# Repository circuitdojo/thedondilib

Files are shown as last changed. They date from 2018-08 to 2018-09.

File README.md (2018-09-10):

# The Dondi Lib

Part nightlight, part art, part Internet of Things. This little bluetooth enabled box will surprise and delight. For more info go [here](https://www.hackster.io/jaredwolff/the-dondi-lib-a-bluetooth-low-energy-light-box-cc7d90).

## Version One

### Features

1. Bluetooth Low Energy with a Rigado BMD-300 (nRF52832)
1. Lithium Battery support
1. Motion support
1. PIR Amplifier (Motion)
1. External connections for button, DC power, battery and PIR
1. Tag-Connect SWD connection

### Rework

Please note that this is Version 1 of the board. There are several (reworkable) issues with this board. 

1. U7A.1 should be connected to D9.C
1. D4.2 should be connected to VDC
1. J2.1 missing connection to VSYS
1. U2 changed to a LED1642GW
1. Untuffed U6 to accomodate LED driver above
1. LED_OE (PWM_CLK) connected to LIS2DH_INT

### License

Released under the Creative Commons Attribution-NonCommercial-NoDerivatives 4.0 International Public License. More info [here](https://creativecommons.org/licenses/by-nc-nd/4.0/legalcode).

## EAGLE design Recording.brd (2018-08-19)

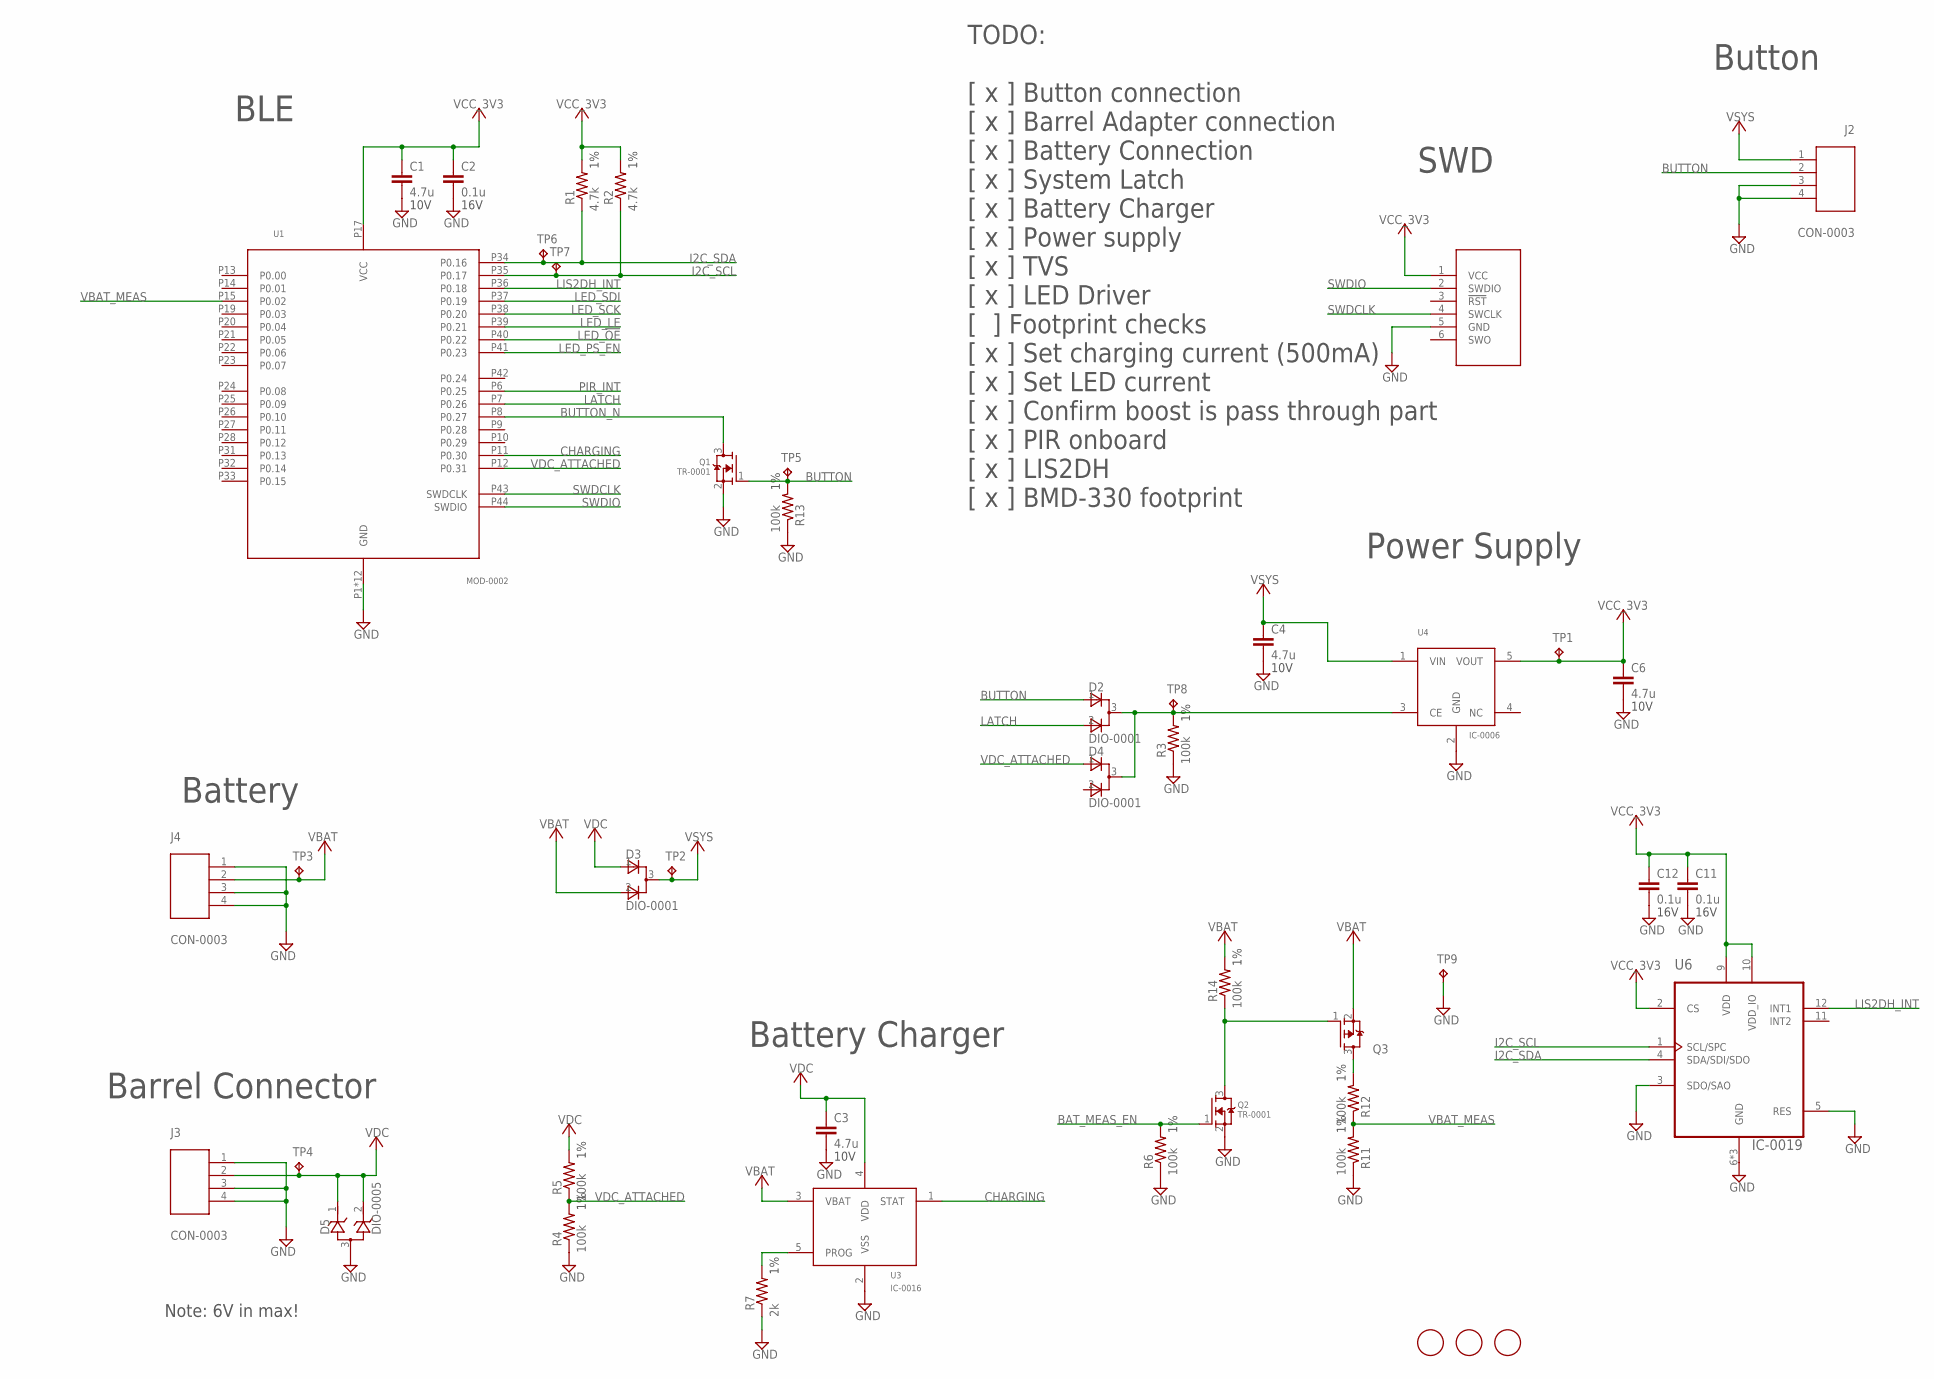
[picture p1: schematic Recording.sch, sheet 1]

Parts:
C1, C3, C4, C6: 4.7u; C0603
C2, C11, C12: 0.1u; C0603
D2, D3, D4: DIO-0001; SOT23
D5: DIO-0005; SOT23
J1: CON-0002; TC2030-MCP-NL
J2, J3, J4: CON-0003; CON-SM02B-SRSS-TB(LF)(SN)
Q1, Q2: TR-0001; SOT23
Q3: TR-0003; SOT23
R1, R2: 4.7k; R0603
R3, R4, R5, R6, R11, R12, R13, R14: 100k; R0603
R7: 2k; R0603
TP1, TP2, TP3, TP4, TP5, TP6, TP7, TP8, TP9: TP-0001; TP-1P27
U1: MOD-0002; MODULE-BMD-300
U3: IC-0016; SOT23-5
U4: IC-0006; SOT23-5
U6: IC-0019; PQFN50P200X200100-12N
U$1, U$2, U$3: FIDUCIAL; FIDUCIAL_1MM

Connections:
BAT_MEAS_EN: Q2.1 (G), R6.2
BAT_MEAS_P_GATE: Q2.3 (D), Q3.1 (G), R14.1
BUTTON: D2.1 (A1), J2.2, Q1.1 (G), R13.2, TP5.P$1, TP5.P$2, TP5.TP
BUTTON_N: Q1.3 (D), U1.P8 (P0.27)
CHARGER_PROG: R7.2, U3.5 (PROG)
CHARGING: U1.P11 (P0.30), U3.1 (STAT)
GND: C1.2, C2.2, C3.2, C4.2, C6.2, C11.2, C12.2, D5.3 (A), J1.5 (GND), J2.3, J2.4, J3.1, J3.3, J3.4, J4.1, J4.3, J4.4, Q1.2 (S), Q2.2 (S), R3.1, R4.1, R6.1, R7.1, R11.1, R13.1, TP9.P$1, TP9.P$2, TP9.TP, U1.P1 (GND), U1.P2 (GND), U1.P3 (GND), U1.P4 (GND), U1.P5 (GND), U1.P16 (GND), U1.P18 (GND), U1.P29 (GND), U1.P30 (GND), U1.P45 (GND), U1.P46 (GND), U1.P47 (GND), U3.2 (VSS), U4.2 (GND), U6.3 (SDO/SAO), U6.5 (RES), U6.6 (GND), U6.7 (GND), U6.8 (GND); also elsewhere on the board
I2C_SCL: R2.1, TP7.P$1, TP7.P$2, TP7.TP, U1.P35 (P0.17), U6.1 (SCL/SPC)
I2C_SDA: R1.1, TP6.P$1, TP6.P$2, TP6.TP, U1.P34 (P0.16), U6.4 (SDA/SDI/SDO)
LATCH: D2.2 (A2), U1.P7 (P0.26)
LED_!OE: U1.P40 (P0.22); also elsewhere on the board
LED_LE: U1.P39 (P0.21); also elsewhere on the board
LED_PS_EN: U1.P41 (P0.23); also elsewhere on the board
LED_SCK: U1.P38 (P0.20); also elsewhere on the board
LED_SDI: U1.P37 (P0.19); also elsewhere on the board
LIS2DH_INT: U1.P36 (P0.18), U6.12 (INT1)
PIR_INT: U1.P6 (P0.25); also elsewhere on the board
SWDCLK: J1.4 (SWCLK), U1.P43 (SWDCLK)
SWDIO: J1.2 (SWDIO), U1.P44 (SWDIO)
VBAT: D3.2 (A2), J4.2, Q3.2 (S), R14.2, TP3.P$1, TP3.P$2, TP3.TP, U3.3 (VBAT)
VBAT_MEAS: R11.2, R12.1, U1.P15 (P0.02)
VBAT_SW: Q3.3 (D), R12.2
VCC_3V3: C1.1, C2.1, C6.1, C11.1, C12.1, J1.1 (VCC), R1.2, R2.2, TP1.P$1, TP1.P$2, TP1.TP, U1.P17 (VCC), U4.5 (VOUT), U6.2 (CS), U6.9 (VDD), U6.10 (VDD_IO); also elsewhere on the board
VCC_3V3_EN: D2.3 (C), D4.3 (C), R3.2, TP8.P$1, TP8.P$2, TP8.TP, U4.3 (CE)
VDC: C3.1, D3.1 (A1), D5.1 (C1), D5.2 (C2), J3.2, R5.2, TP4.P$1, TP4.P$2, TP4.TP, U3.4 (VDD)
VDC_ATTACHED: D4.1 (A1), R4.2, R5.1, U1.P12 (P0.31)
VSYS: C4.1, D3.3 (C), TP2.P$1, TP2.P$2, TP2.TP, U4.1 (VIN); also elsewhere on the board

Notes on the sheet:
TODO: [ x ] Button connection [ x ] Barrel Adapter connection [ x ] Battery Connection [ x ] System Latch [ x ] Battery Charger [ x ] Power supply [ x ] TVS [ x ] LED Driver [ ] Footprint checks [ x ] Set charging current (500mA) [ x ] Set LED current [ x ] Confirm boost is pass through part [ x ] 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
Button
SWD
BLE
Battery
Barrel Connector
Note: 6V in max!
Battery Charger
Power Supply

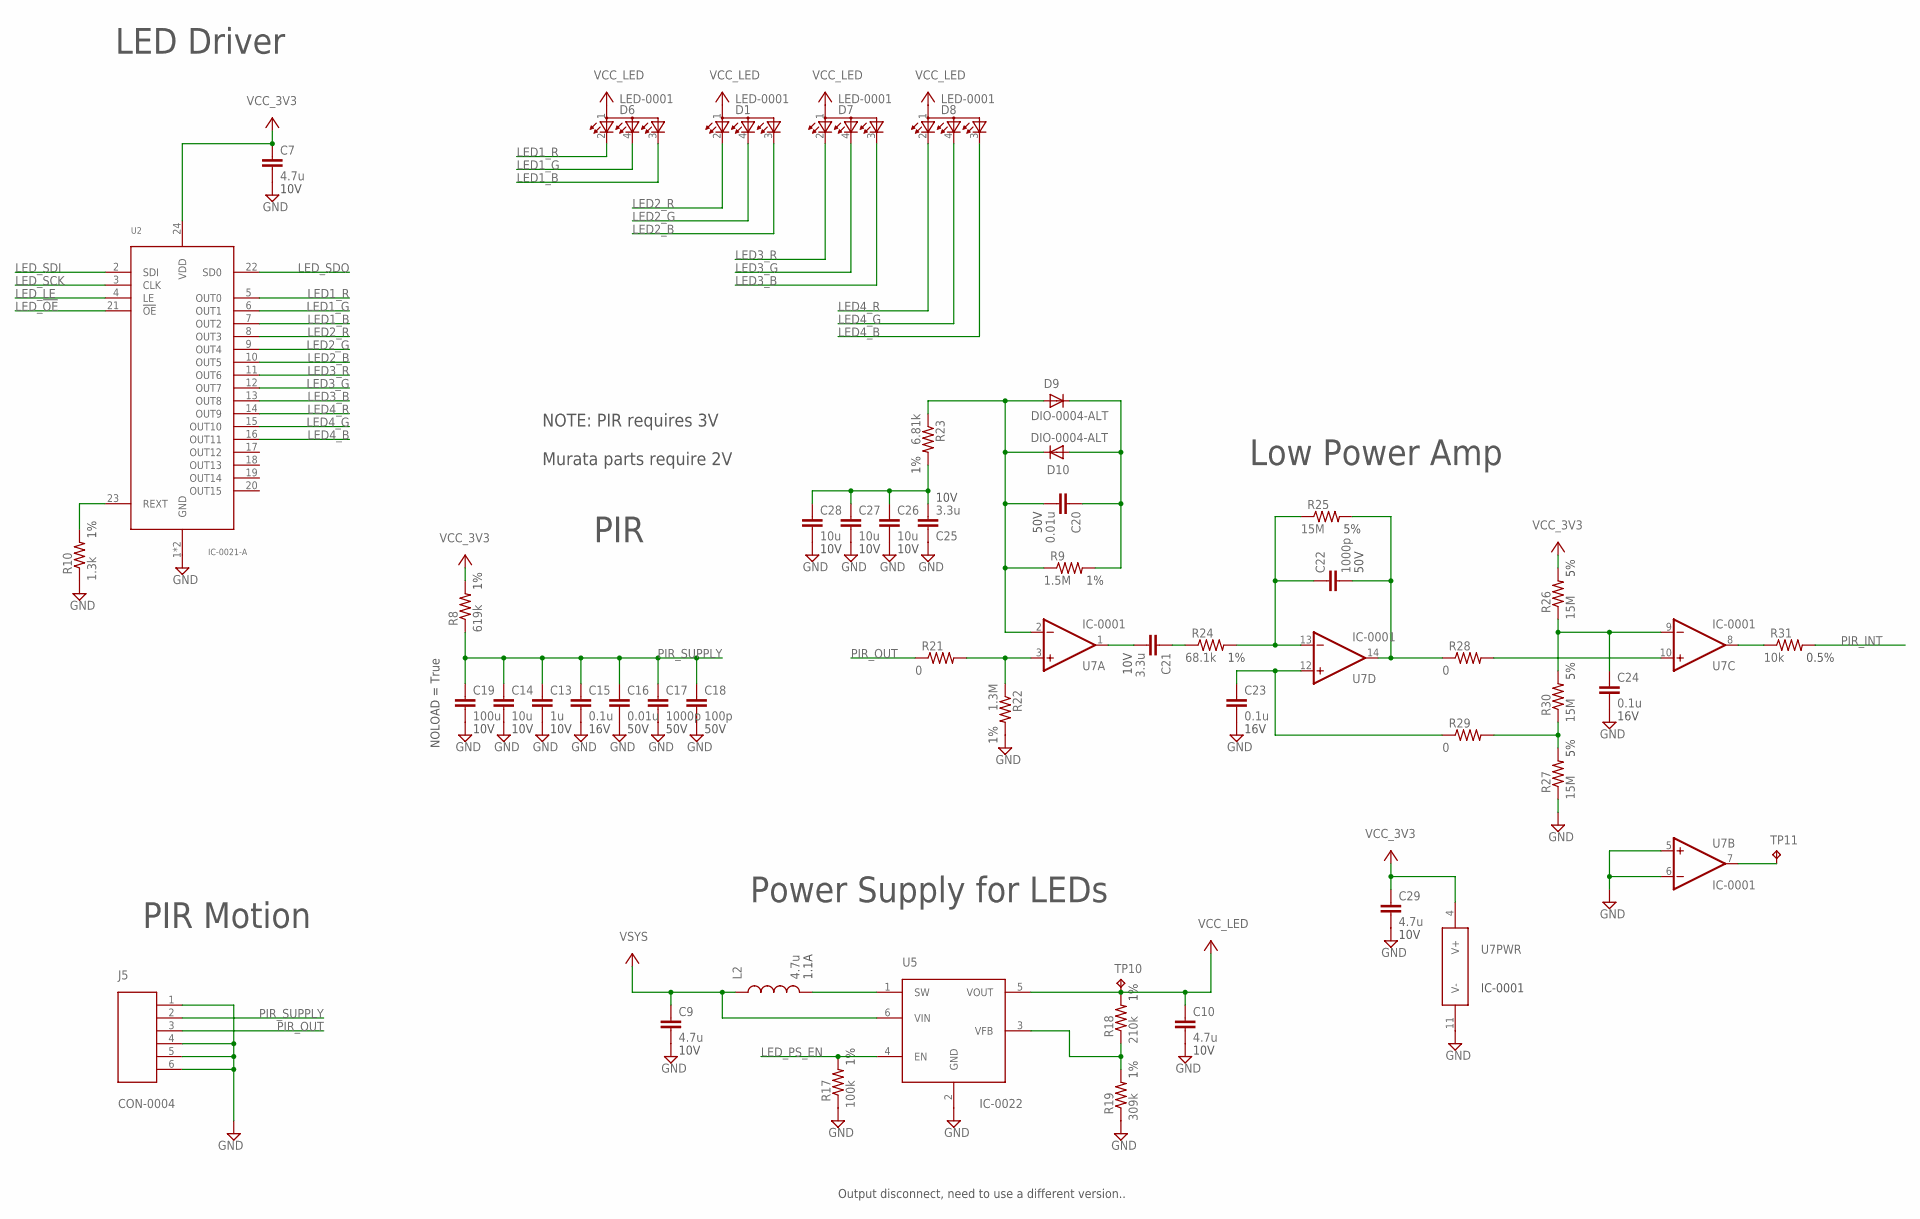
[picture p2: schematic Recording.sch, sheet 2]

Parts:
C7, C9, C10, C29: 4.7u; C0603
C13: 1u; C0603
C14, C26, C27, C28: 10u; C0805
C15, C23, C24: 0.1u; C0603
C16, C20: 0.01u; C0603
C17, C22: 1000p; C0603
C18: 100p; C0603
C19: 100u; C1210
C21, C25: 3.3u; C0603
D1, D6, D7, D8: LED-0001; LED_ASMB-KTF0-0A306
D9, D10: DIO-0004-ALT; SOD523
J5: CON-0004; CON-SM04B-SRSS-TB(LF)(SN)
L2: 4.7u; IND-2P0X2P0X1P2
R8: 619k; R0603
R9: 1.5M; R0603
R10: 1.3k; R0603
R17: 100k; R0603
R18: 210k; R0603
R19: 309k; R0603
R21, R28, R29: 0; R0603
R22: 1.3M; R0603
R23: 6.81k; R0603
R24: 68.1k; R0603
R25, R26, R27, R30: 15M; R0603
R31: 10k; R0603
TP10, TP11: TP-0001; TP-1P27
U2: IC-0021-A; SOP65P640X120-25N
U5: IC-0022; SOT23-6
U7: IC-0001; TSSOP14

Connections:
BOOST_FB: R18.1, R19.2, U5.3 (VFB)
BOOST_SW: L2.P$2 (2), U5.1 (SW)
GND: C7.2, C9.2, C10.2, C13.2, C14.2, C15.2, C16.2, C17.2, C18.2, C19.2, C23.2, C24.2, C25.1, C26.2, C27.2, C28.2, C29.2, J5.1, J5.4, J5.5, J5.6, R10.1, R17.1, R19.1, R22.2, R27.1, U2.1 (GND), U2.25 (GND), U5.2 (GND), U7.5 (+IN), U7.6 (-IN), U7.11 (V-); also elsewhere on the board
LED1_B: D6.3 (CGREEN), U2.7 (OUT2)
LED1_G: D6.4 (CBLUE), U2.6 (OUT1)
LED1_R: D6.2 (CRED), U2.5 (OUT0)
LED2_B: D1.3 (CGREEN), U2.10 (OUT5)
LED2_G: D1.4 (CBLUE), U2.9 (OUT4)
LED2_R: D1.2 (CRED), U2.8 (OUT3)
LED3_B: D7.3 (CGREEN), U2.13 (OUT8)
LED3_G: D7.4 (CBLUE), U2.12 (OUT7)
LED3_R: D7.2 (CRED), U2.11 (OUT6)
LED4_B: D8.3 (CGREEN), U2.16 (OUT11)
LED4_G: D8.4 (CBLUE), U2.15 (OUT10)
LED4_R: D8.2 (CRED), U2.14 (OUT9)
LED_!OE: U2.21 (!OE); also elsewhere on the board
LED_LE: U2.4 (LE); also elsewhere on the board
LED_PS_EN: R17.2, U5.4 (EN); also elsewhere on the board
LED_REXT: R10.2, U2.23 (REXT)
LED_SCK: U2.3 (CLK); also elsewhere on the board
LED_SDI: U2.2 (SDI); also elsewhere on the board
LED_SDO: U2.22 (SD0)
unnamed: C20.2, D9.A, D10.C, R9.1, R23.1, U7.2 (-IN)
unnamed: TP11.P$1, TP11.P$2, TP11.TP, U7.7 (OUT)
unnamed: C20.1, D9.C, D10.A, R9.2
unnamed: R21.2, R22.1, U7.3 (+IN)
unnamed: C25.2, C26.1, C27.1, C28.1, R23.2
unnamed: C21.2, U7.1 (OUT)
unnamed: C21.1, R24.1
unnamed: C22.1, R24.2, R25.1, U7.13 (-IN)
unnamed: C22.2, R25.2, R28.1, U7.14 (OUT)
unnamed: C23.1, R29.1, U7.12 (+IN)
unnamed: R28.2, U7.10 (+IN)
unnamed: R27.2, R29.2, R30.1
unnamed: C24.1, R26.1, R30.2, U7.9 (-IN)
PIR_INT: R31.2; also elsewhere on the board
PIR_INT_CL: R31.1, U7.8 (OUT)
PIR_OUT: J5.3, R21.1
PIR_SUPPLY: C13.1, C14.1, C15.1, C16.1, C17.1, C18.1, C19.1, J5.2, R8.1
VCC_3V3: C7.1, C29.1, R8.2, R26.2, U2.24 (VDD), U7.4 (V+); also elsewhere on the board
VCC_LED: C10.1, D1.1 (A2), D6.1 (A2), D7.1 (A2), D8.1 (A2), R18.2, TP10.P$1, TP10.P$2, TP10.TP, U5.5 (VOUT)
VSYS: C9.1, L2.P$1 (1), U5.6 (VIN); also elsewhere on the board

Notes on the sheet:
PIR Motion
Power Supply for LEDs
LED Driver
PIR
Low Power Amp
NOTE: PIR requires 3V Murata parts require 2V
Output disconnect, need to use a different version..

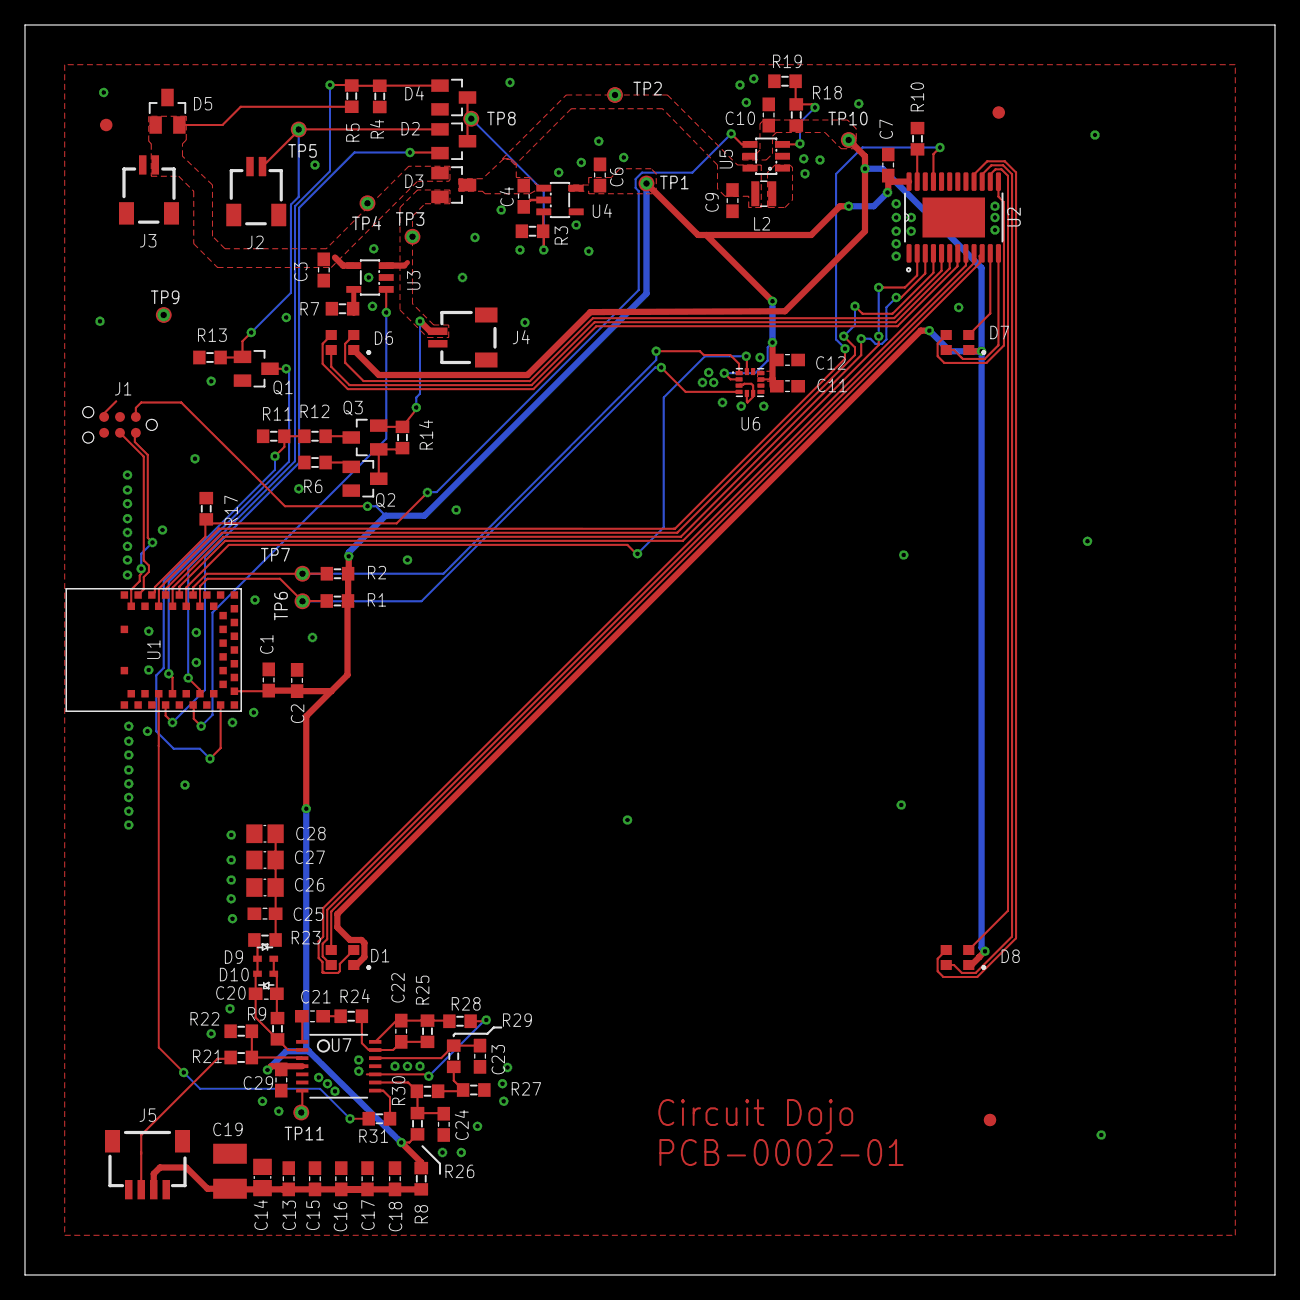
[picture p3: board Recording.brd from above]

Board: 2 copper layers, 100.0 x 100.0 mm, 95 parts (0 on the bottom side), 59 nets.

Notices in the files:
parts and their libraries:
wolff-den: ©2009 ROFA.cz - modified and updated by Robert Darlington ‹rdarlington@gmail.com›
